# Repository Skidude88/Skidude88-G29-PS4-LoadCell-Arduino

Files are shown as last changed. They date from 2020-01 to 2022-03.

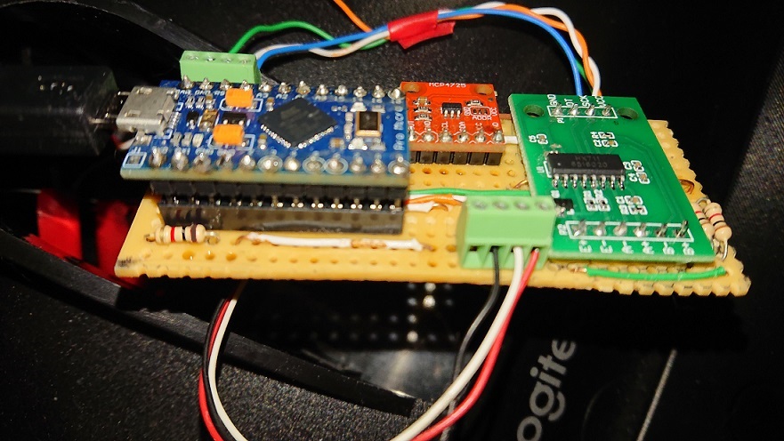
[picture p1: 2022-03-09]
img/Final Build - Clutch Resistor.jpg

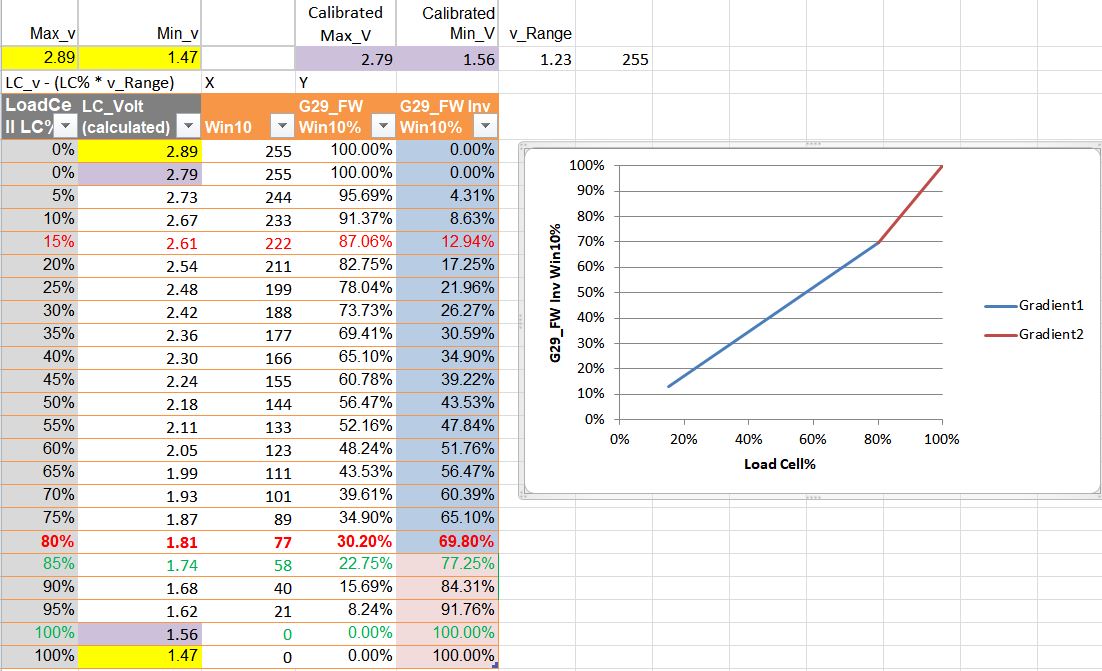
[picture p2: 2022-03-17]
img/New Testing.JPG

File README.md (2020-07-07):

# Skidude88-G29-PS4-LoadCell-Arduino
DIY load cell conversion for Logitech G29 on PS4 using Arduino Pro Micro. On Gran Tourismo Sport, where no manual in-game device calibration is availiable.

This Project was developed in conjunction with an analog DIY load cell version by GeekyDeaks

https://github.com/GeekyDeaks/g29-load-cell

# For full info on this project please refer to the project Wiki Pages

The final working project is with a single load cell and a MCP4725 - DAC

For the Pedal 3D print files - Please see the aforementioned GeekyDeaks project pages

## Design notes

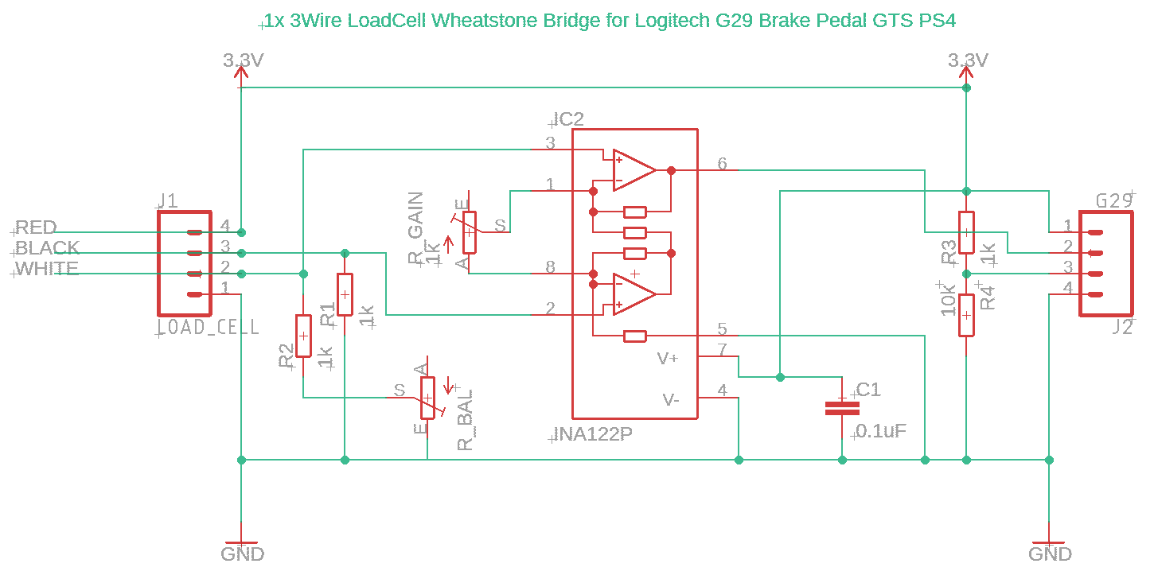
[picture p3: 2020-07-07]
img/Single 3WireLoadCellSchematic.PNG

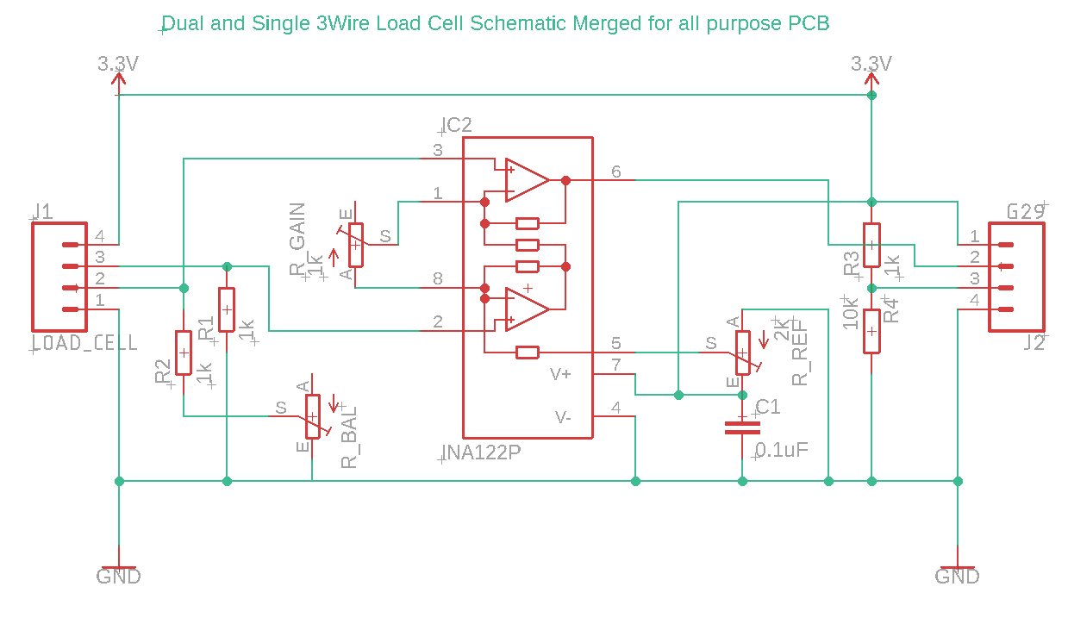
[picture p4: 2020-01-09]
img/Dual and Single LoadCell Schematic For MultiPurp PCB.PNG

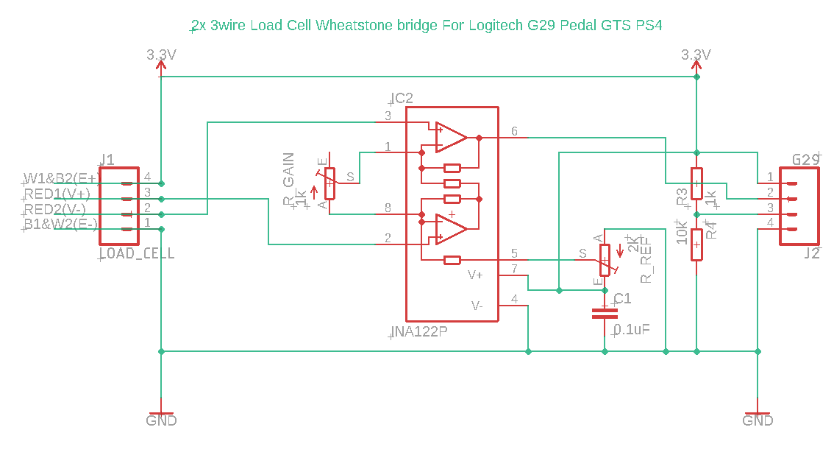
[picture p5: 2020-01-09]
img/2x3WireLoadCellSchematic.PNG

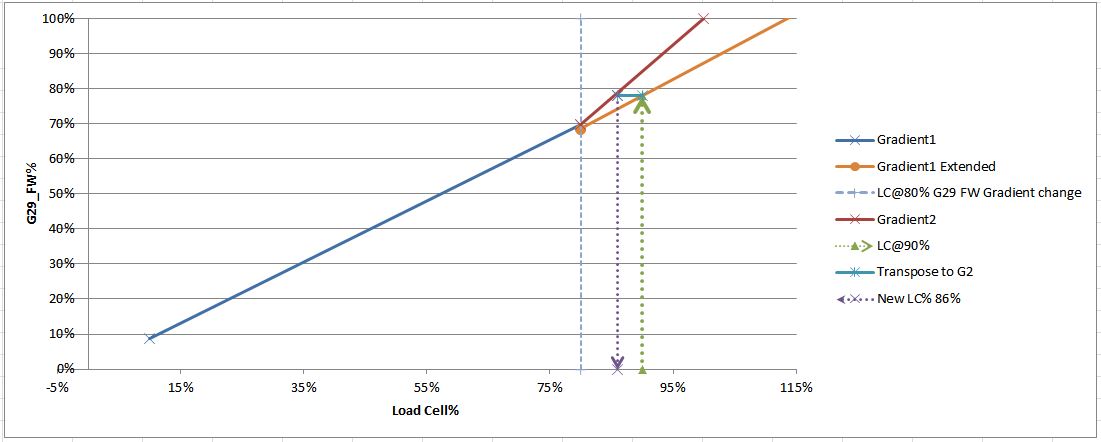
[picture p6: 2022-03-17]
img/New Table-Graph.JPG

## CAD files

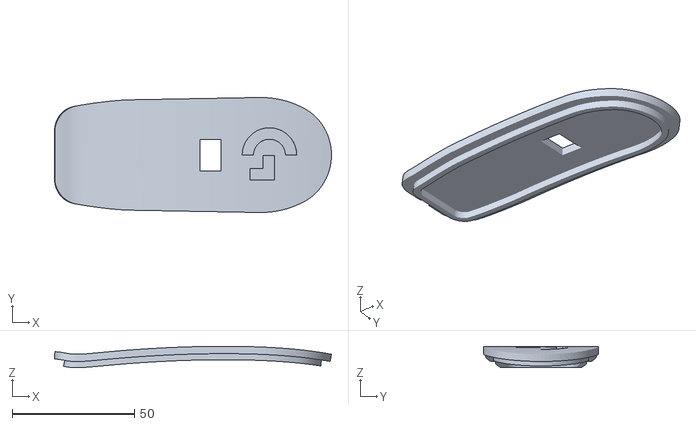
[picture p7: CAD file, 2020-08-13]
stl/G29 Brake Pedal Cover - USB.stl
113.1 x 47.0 x 8.76

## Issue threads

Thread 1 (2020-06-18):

PC/PS4 and G25/G27/G29 Compatibility.

isopix, 2020-06-18:
Hi,

I guess that yes, but wanted to make sure that's compatible with both PC and PS4 without any recalibration? Is it WIP, or is it solution that already progress.

I'm also wondering if it's needed only for G29 pedals because progressive brake curve(so called 'load cell emulation'), and without your board cell-modded G25/G27 pedals would work without any issues?

Overally your repo lacks clear documentation, or at least easy readme which would point to correct schematic/code/firmware blob. I saw different schematics, one with four chips/two arduinos(I don't understand what 'IPS' there means) and I don't know which should I use/ what should I buy.

Anyway thanks for your great work!

GeekyDeaks, 2020-06-18:
Hey @isopix - not sure if you found it, but @Skidude88 put most of his thoughts in the wiki rather than the README https://github.com/Skidude88/Skidude88-G29-PS4-LoadCell-Arduino/wiki

His design worked by emulating the voltage levels of the standard pot, so that the pedals could still be directly connected to the G29 wheel.  I believe you can tweak the constants for the max and min in the code e.g.

https://github.com/Skidude88/Skidude88-G29-PS4-LoadCell-Arduino/blob/5b6c035fbedb372972704d26ac1def72356d9f96/Code/SimPedal_ver3_dac.ino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

Please note that it's not actually trying to workaround the progressive brake curve of the G29, but it could in theory.  The circuit would still be required for a G25/G27 since the loadcell used is just a pair of resistors that change value by a very small amount when a load is applied, so you need something to measure the change and convert it to a voltage

I think when you mentioned IPS you may have been referring to the ISP code?  This is an auxillary arduino project that turns an arduino into an in-circuit programmer.  I this was required because the G29 actually supplies 3.3v to the pedals, and the arduino used needed some fuses set to work properly at 3.3v and they could not be set via the bootloader mechanism, so a spare arduino was configured as an ISP to program the target arduino, which is probably why you see two of them!

Skidude88, 2020-06-18:
Hi isopix,

Thanks for pointing out the IPS file name typo - should be "ISP" - In System Programmer - detailed in the 2nd Wiki: here:

[https://github.com/Skidude88/Skidude88-G29-PS4-LoadCell-Arduino/wiki/Arduino-Pro-Micro-with-a-Broken-USB-connector](url)

I only used two Arduino's after breaking the original.  The wiki on how to use a 2nd Arduino to Program another was included as an out of interest additional, sub project.

I can't see why it wouldn't work on a PC, the mod is only replacing the variable resistor pot , spring & flaky rubber block - converting the load cell output to voltage values required. The PC wouldn't know any different.

The project wasn't used\tested\tried on one. I only ran on a PS4 and Gran Turismo Sport.

I've made a few tweaks to the wiki , that may  (or may not) make things a little clearer!

Skidude88, 2020-06-18:
Re WIP

This was a finished project.

Though I am running @GeekyDeaks Analogue version of our project - only because we'd tinkered making home made PCBs .

And it's just a bit of a faff to keep connecting up the 2nd Arduino to program the  other and setting the 5v board to run a 3.3v (and the lower frequency) each time.

If I'd got a 3.3v board version I'd probably run with that as it just connect straight up to USB on PC

isopix, 2020-06-18:
Ok, thank you both for the reply. I didn't know about the Wiki there.

I found @GeekyDeaks your repo yesterday and that you are selling PCBs for it. Wanted to ask if you live within EU and what would be the price of PCB with shipping to Poland. I've later found TrueBrake and now not sure what to choose:

1) GeekyDeaks DIY LoadCell
+ real load cell (much more reliable than any pot-based solution?)
+ ?price (it's unknown ;-)
- not compact DIY hard to install
- 3D printed body(fragile?)
- not G29 firendly because progressive curve, but according to @GeekyDeaks it can be corrected in firmware

2) TrueBrake
+ easy to install
+ durable body
+ compact
- not really G29  friendly(because G29 pedals firmware[or maybe it's wheel firmware?) output got progressive curve, and it's dumb pot output)
- not real load cell
- pot based(and whe know that pot wears after time. Why not hall-effect rotary position sensor in place of pot?) Is it easy to buy off-the-shelf part?
- pricey (mine g29+shifter+stand in mint condition costed 120GBP, while TrueBrake costs 71GBP with VAT+shipping to Poland)

3) Ricmotech LC27 Load Cell Conversion Kit
+ real load cell
+ ricmotech quality
+ compact and easy to install
- not really G29  friendly(because G29 pedals firmware[or maybe it's wheel firmware?) output got progressive curve, and it's dumb pot output)
- $130 is nearly as much as  I've paid for G29+shifter+stand combo, so it's proabably designed

So as I understand no solution would be ideal with G29 progressive output curve in firmware, so maybe the best idea would be to exchange G29 pedals for G27 one, which got linear output curve, right? (Or maybe G27 pedals firmware could be dumped and programmed into G29? or maybe it's wheel firmware, not pedals firmware?)

I will post this questions in racedepartment too, wonder about AXC SIM's response.

GeekyDeaks, 2020-06-18:
Hi @isopix

I would not worry too much about the mapping of the G29 wheel on the brake voltage. output.  We plotted it out and it's not particularly aggressive and more a gentle curve.

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

If you plan to use it with a PC and you have a spare arduino, then you might want to consider something like this to bypass the wheel https://github.com/n-e-y-s/G27_Pedals_and_Shifter

TrueBrake is a fairly low-cost option, especially if you just want to improve the pedal and not take on a project to tinker with! :). It is still a pot, but it's not as exposed as those in the G29/G27 etc, so I would not expect it to suffer the same issues with dust.

If you want to go the DIY option and would like a PCB, PM me in racedepartment and I'll post one over foc.

Skidude88, 2020-06-19:
The 3D printed body is REALLY tough. A friend made it, so I can't give specifics on the type of plastic material used.

GeekyDeaks, 2020-06-19:
I'm surprised you did not elaborate on the reason why you know first hand that it's really tough 😄

Skidude88, 2020-06-19:
Ha!  I originally put I've a scar to prove it, but deleted the comment 😄

jhoman81, 2020-07-04:
I have a few questions about this setup. First, should this work without any modifications with the G27? I don't know enough about electronics to even know where to start looking for the answer to that question so hopefully you have some insight. Also, is the hx711 library you're using the one referenced in the file (https://github.com/aguegu/ardulibs/tree/master/hx711) or the one from https://github.com/bogde/HX711, because I can only get it to verify/upload with the latter. Finally, does it have to be connected to the G27/G29 do get values through the serial port? I think I have mine wired up correctly but I have getting 0 information back from the serial monitor. Any help is greatly appreciated! Thanks!

Skidude88, 2020-07-05:
Hi Joshua,

I can't find your message on github, despite selecting the "view it on Github" on the email (I'm new to Github! )

I couldn't recall where the libraries are - so I've just quickly loaded up and complied with the debugger on...

I believe you're correct - I have incorrectly listed the library!

The compiler references : HX711-0.7.3@0.7.2 - Which a quick google seems to be the bogde you've mentioned.

I'll get the wiki and code updated asap!

With regards to your other questions :

I only have a G29, so can't confirm that the voltages the G27 pedal outputs are the same as the G29.

From memory the G29 off is 3.1v and 100% brake on was around 2v

Someone might have posted on the web the values for the G27 - so a bit of googling might be required.

Or with a multi-meter you could check your pedal's pot voltage output.

If the voltages are different then it would just be a case of changing the BrakeFull_v and BrakeOff_v variable values in the code to suit.

The project doesn't need to be connected up to the wheel to see the calculated values on the serial monitor\plotter, just enable the relevant serial.println line in the code  (depending on what value you want to monitor : BrakeValue or Percent)

Kind Regards,

James

________________________________
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

jhoman81, 2020-07-07:
Hola James,

Sorry! It was late and I wanted to make sure I had done everything correctly so I deleted the old post. What you posted, however, is extremely helpful! Thanks! I should have some free time to try this out tomorrow with the G27 pedals and will let you know what I figure out. I've gone ahead and forked your repository to begin shifting it to the G27. Thanks again!

Saludos,
Josh

GeekyDeaks, 2020-07-08:
Hi Josh,

I'm assuming you are using this on a PC?  If so, I also have another suggestion, but feel free to ignore it :)

A lot of the hard work James did was in getting a correct and stable voltage out of the Arduino for the ADC in the wheel to read so it could still be used on a PS4.  If you are on PC, then you have the option to connect the pedals directly to the PC using the Arduino to emulate a game controller (e.g. https://github.com/functionreturnfunction/G27_Pedals_and_Shifter) adding the code James created to read the HX711 as one of the axis.

This makes the entire solution digital, removing the need for the DAC or the low pass filter with PWM.  This will simplify the circuit and give you a little more flexibility with the pedal ranges, but it also means you have more work to do in the software instead

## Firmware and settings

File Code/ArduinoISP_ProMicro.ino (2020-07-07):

// ArduinoISP
// Copyright (c) 2008-2011 Randall Bohn
// If you require a license, see
// http://www.opensource.org/licenses/bsd-license.php
//
// This sketch turns the Arduino into a AVRISP using the following Arduino pins:
//
// Pin 10 is used to reset the target microcontroller.
//
// By default, the hardware SPI pins MISO, MOSI and SCK are used to communicate
// with the target. On all Arduinos, these pins can be found
// on the ICSP/SPI header:
//
//               MISO °. . 5V (!) Avoid this pin on Due, Zero...
//               SCK   . . MOSI
//                     . . GND
//
// On some Arduinos (Uno,...), pins MOSI, MISO and SCK are the same pins as
// digital pin 11, 12 and 13, respectively. That is why many tutorials instruct
// you to hook up the target to these pins. If you find this wiring more
// practical, have a define USE_OLD_STYLE_WIRING. This will work even when not
// using an Uno. (On an Uno this is not needed).
//
// Alternatively you can use any other digital pin by configuring
// software ('BitBanged') SPI and having appropriate defines for PIN_MOSI,
// PIN_MISO and PIN_SCK.
//
// IMPORTANT: When using an Arduino that is not 5V tolerant (Due, Zero, ...) as
// the programmer, make sure to not expose any of the programmer's pins to 5V.
// A simple way to accomplish this is to power the complete system (programmer
// and target) at 3V3.
//
// Put an LED (with resistor) on the following pins:
// 9: Heartbeat   - shows the programmer is running
// 8: Error       - Lights up if something goes wrong (use red if that makes sense)
// 7: Programming - In communication with the slave
//

#include "Arduino.h"
#undef SERIAL


#define PROG_FLICKER true

// Configure SPI clock (in Hz).
// E.g. for an ATtiny @ 128 kHz: the datasheet states that both the high and low
// SPI clock pulse must be > 2 CPU cycles, so take 3 cycles i.e. divide target
// f_cpu by 6:
//     #define SPI_CLOCK            (128000/6)
//
// A clock slow enough for an ATtiny85 @ 1 MHz, is a reasonable default:

#define SPI_CLOCK 		(1000000/6)


// Select hardware or software SPI, depending on SPI clock.
// Currently only for AVR, for other architectures (Due, Zero,...), hardware SPI
// is probably too fast anyway.

#if defined(ARDUINO_ARCH_AVR)

#if SPI_CLOCK > (F_CPU / 128)
#define USE_HARDWARE_SPI
#endif

#endif

// Configure which pins to use:

// The standard pin configuration.
#ifndef ARDUINO_HOODLOADER2

#define RESET     10 // Use pin 10 to reset the target rather than SS
#define LED_HB    9
#define LED_ERR   8
#define LED_PMODE 7

// Uncomment following line to use the old Uno style wiring
// (using pin 11, 12 and 13 instead of the SPI header) on Leonardo, Due...

#define USE_OLD_STYLE_WIRING

#ifdef USE_OLD_STYLE_WIRING

//#define PIN_MOSI	11
//#define PIN_MISO	12
//#define PIN_SCK		13

#define PIN_MOSI  16
#define PIN_MISO  14
#define PIN_SCK   15


#endif

// HOODLOADER2 means running sketches on the ATmega16U2 serial converter chips
// on Uno or Mega boards. We must use pins that are broken out:
#else

#define RESET     	4
#define LED_HB    	7
#define LED_ERR   	6
#define LED_PMODE 	5

#endif

// By default, use hardware SPI pins:
#ifndef PIN_MOSI
#define PIN_MOSI 	MOSI
#endif

#ifndef PIN_MISO
#define PIN_MISO 	MISO
#endif

#ifndef PIN_SCK
#define PIN_SCK 	SCK
#endif

// Force bitbanged SPI if not using the hardware SPI pins:
#if (PIN_MISO != MISO) ||  (PIN_MOSI != MOSI) || (PIN_SCK != SCK)
#undef USE_HARDWARE_SPI
#endif


// Configure the serial port to use.
//
// Prefer the USB virtual serial port (aka. native USB port), if the Arduino has one:
//   - it does not autoreset (except for the magic baud rate of 1200).
//   - it is more reliable because of USB handshaking.
//
// Leonardo and similar have an USB virtual serial port: 'Serial'.
// Due and Zero have an USB virtual serial port: 'SerialUSB'.
//
// On the Due and Zero, 'Serial' can be used too, provided you disable autoreset.
// To use 'Serial': #define SERIAL Serial

#ifdef SERIAL_PORT_USBVIRTUAL
#define SERIAL SERIAL_PORT_USBVIRTUAL
#else
#define SERIAL Serial
#endif


// Configure the baud rate:

#define BAUDRATE	19200
// #define BAUDRATE	115200
// #define BAUDRATE	1000000


#define HWVER 2
#define SWMAJ 1
#define SWMIN 18

// STK Definitions
#define STK_OK      0x10
#define STK_FAILED  0x11
#define STK_UNKNOWN 0x12
#define STK_INSYNC  0x14
#define STK_NOSYNC  0x15
#define CRC_EOP     0x20 //ok it is a space...

void pulse(int pin, int times);

#ifdef USE_HARDWARE_SPI
#include "SPI.h"
#else

#define SPI_MODE0 0x00

class SPISettings {
  public:
    // clock is in Hz
    SPISettings(uint32_t clock, uint8_t bitOrder, uint8_t dataMode) : clock(clock) {
      (void) bitOrder;
      (void) dataMode;
    };

  private:
    uint32_t clock;

    friend class BitBangedSPI;
};

class BitBangedSPI {
  public:
    void begin() {
      digitalWrite(PIN_SCK, LOW);
      digitalWrite(PIN_MOSI, LOW);
      pinMode(PIN_SCK, OUTPUT);
      pinMode(PIN_MOSI, OUTPUT);
      pinMode(PIN_MISO, INPUT);
    }

    void beginTransaction(SPISettings settings) {
      pulseWidth = (500000 + settings.clock - 1) / settings.clock;
      if (pulseWidth == 0)
        pulseWidth = 1;
    }

    void end() {}

    uint8_t transfer (uint8_t b) {
      for (unsigned int i = 0; i < 8; ++i) {
        digitalWrite(PIN_MOSI, (b & 0x80) ? HIGH : LOW);
        digitalWrite(PIN_SCK, HIGH);
        delayMicroseconds(pulseWidth);
        b = (b << 1) | digitalRead(PIN_MISO);
        digitalWrite(PIN_SCK, LOW); // slow pulse
        delayMicroseconds(pulseWidth);
      }
      return b;
    }

  private:
    unsigned long pulseWidth; // in microseconds
};

static BitBangedSPI SPI;

#endif

void setup() {
  SERIAL.begin(BAUDRATE);

  pinMode(LED_PMODE, OUTPUT);
  pulse(LED_PMODE, 2);
  pinMode(LED_ERR, OUTPUT);
  pulse(LED_ERR, 2);
  pinMode(LED_HB, OUTPUT);
  pulse(LED_HB, 2);

}

int error = 0;
int pmode = 0;
// address for reading and writing, set by 'U' command
unsigned int here;
uint8_t buff[256]; // global block storage

#define beget16(addr) (*addr * 256 + *(addr+1) )
typedef struct param {
  uint8_t devicecode;
  uint8_t revision;
  uint8_t progtype;
  uint8_t parmode;
  uint8_t polling;
  uint8_t selftimed;
  uint8_t lockbytes;
  uint8_t fusebytes;
  uint8_t flashpoll;
  uint16_t eeprompoll;
  uint16_t pagesize;
  uint16_t eepromsize;
  uint32_t flashsize;
}
parameter;

parameter param;

// this provides a heartbeat on pin 9, so you can tell the software is running.
uint8_t hbval = 128;
int8_t hbdelta = 8;
void heartbeat() {
  static unsigned long last_time = 0;
  unsigned long now = millis();
  if ((now - last_time) < 40)
    return;
  last_time = now;
  if (hbval > 192) hbdelta = -hbdelta;
  if (hbval < 32) hbdelta = -hbdelta;
  hbval += hbdelta;
  analogWrite(LED_HB, hbval);
}

static bool rst_active_high;

void reset_target(bool reset) {
  digitalWrite(RESET, ((reset && rst_active_high) || (!reset && !rst_active_high)) ? HIGH : LOW);
}

void loop(void) {
  // is pmode active?
  if (pmode) {
    digitalWrite(LED_PMODE, HIGH);
  } else {
    digitalWrite(LED_PMODE, LOW);
  }
  // is there an error?
  if (error) {
    digitalWrite(LED_ERR, HIGH);
  } else {
    digitalWrite(LED_ERR, LOW);
  }

  // light the heartbeat LED
  heartbeat();
  if (SERIAL.available()) {
    avrisp();
  }
}

uint8_t getch() {
  while (!SERIAL.available());
  return SERIAL.read();
}
void fill(int n) {
  for (int x = 0; x < n; x++) {
    buff[x] = getch();
  }
}

#define PTIME 30
void pulse(int pin, int times) {
  do {
    digitalWrite(pin, HIGH);
    delay(PTIME);
    digitalWrite(pin, LOW);
    delay(PTIME);
  } while (times--);
}

void prog_lamp(int state) {
  if (PROG_FLICKER) {
    digitalWrite(LED_PMODE, state);
  }
}

uint8_t spi_transaction(uint8_t a, uint8_t b, uint8_t c, uint8_t d) {
  SPI.transfer(a);
  SPI.transfer(b);
  SPI.transfer(c);
  return SPI.transfer(d);
}

void empty_reply() {
  if (CRC_EOP == getch()) {
    SERIAL.print((char)STK_INSYNC);
    SERIAL.print((char)STK_OK);
  } else {
    error++;
    SERIAL.print((char)STK_NOSYNC);
  }
}

void breply(uint8_t b) {
  if (CRC_EOP == getch()) {
    SERIAL.print((char)STK_INSYNC);
    SERIAL.print((char)b);
    SERIAL.print((char)STK_OK);
  } else {
    error++;
    SERIAL.print((char)STK_NOSYNC);
  }
}

void get_version(uint8_t c) {
  switch (c) {
    case 0x80:
      breply(HWVER);
      break;
    case 0x81:
      breply(SWMAJ);
      break;
    case 0x82:
      breply(SWMIN);
      break;
    case 0x93:
      breply('S'); // serial programmer
      break;
    default:
      breply(0);
  }
}

void set_parameters() {
  // call this after reading parameter packet into buff[]
  param.devicecode = buff[0];
  param.revision   = buff[1];
  param.progtype   = buff[2];
  param.parmode    = buff[3];
  param.polling    = buff[4];
  param.selftimed  = buff[5];
  param.lockbytes  = buff[6];
  param.fusebytes  = buff[7];
  param.flashpoll  = buff[8];
  // ignore buff[9] (= buff[8])
  // following are 16 bits (big endian)
  param.eeprompoll = beget16(&buff[10]);
  param.pagesize   = beget16(&buff[12]);
  param.eepromsize = beget16(&buff[14]);

  // 32 bits flashsize (big endian)
  param.flashsize = buff[16] * 0x01000000
                    + buff[17] * 0x00010000
                    + buff[18] * 0x00000100
                    + buff[19];

  // AVR devices have active low reset, AT89Sx are active high
  rst_active_high = (param.devicecode >= 0xe0);
}

void start_pmode() {

  // Reset target before driving PIN_SCK or PIN_MOSI

  // SPI.begin() will configure SS as output, so SPI master mode is selected.
  // We have defined RESET as pin 10, which for many Arduinos is not the SS pin.
  // So we have to configure RESET as output here,
  // (reset_target() first sets the correct level)
  reset_target(true);
  pinMode(RESET, OUTPUT);
  SPI.begin();
  SPI.beginTransaction(SPISettings(SPI_CLOCK, MSBFIRST, SPI_MODE0));

  // See AVR datasheets, chapter "SERIAL_PRG Programming Algorithm":

  // Pulse RESET after PIN_SCK is low:
  digitalWrite(PIN_SCK, LOW);
  delay(20); // discharge PIN_SCK, value arbitrarily chosen
  reset_target(false);
  // Pulse must be minimum 2 target CPU clock cycles so 100 usec is ok for CPU
  // speeds above 20 KHz
  delayMicroseconds(100);
  reset_target(true);

  // Send the enable programming command:
  delay(50); // datasheet: must be > 20 msec
  spi_transaction(0xAC, 0x53, 0x00, 0x00);
  pmode = 1;
}

void end_pmode() {
  SPI.end();
  // We're about to take the target out of reset so configure SPI pins as input
  pinMode(PIN_MOSI, INPUT);
  pinMode(PIN_SCK, INPUT);
  reset_target(false);
  pinMode(RESET, INPUT);
  pmode = 0;
}

void universal() {
  uint8_t ch;

  fill(4);
  ch = spi_transaction(buff[0], buff[1], buff[2], buff[3]);
  breply(ch);
}

void flash(uint8_t hilo, unsigned int addr, uint8_t data) {
  spi_transaction(0x40 + 8 * hilo,
                  addr >> 8 & 0xFF,
                  addr & 0xFF,
                  data);
}
void commit(unsigned int addr) {
  if (PROG_FLICKER) {
    prog_lamp(LOW);
  }
  spi_transaction(0x4C, (addr >> 8) & 0xFF, addr & 0xFF, 0);
  if (PROG_FLICKER) {
    delay(PTIME);
    prog_lamp(HIGH);
  }
}

unsigned int current_page() {
  if (param.pagesize == 32) {
    return here & 0xFFFFFFF0;
  }
  if (param.pagesize == 64) {
    return here & 0xFFFFFFE0;
  }
  if (param.pagesize == 128) {
    return here & 0xFFFFFFC0;
  }
  if (param.pagesize == 256) {
    return here & 0xFFFFFF80;
  }
  return here;
}


void write_flash(int length) {
  fill(length);
  if (CRC_EOP == getch()) {
    SERIAL.print((char) STK_INSYNC);
    SERIAL.print((char) write_flash_pages(length));
  } else {
    error++;
    SERIAL.print((char) STK_NOSYNC);
  }
}

uint8_t write_flash_pages(int length) {
  int x = 0;
  unsigned int page = current_page();
  while (x < length) {
    if (page != current_page()) {
      commit(page);
      page = current_page();
    }
    flash(LOW, here, buff[x++]);
    flash(HIGH, here, buff[x++]);
    here++;
  }

  commit(page);

  return STK_OK;
}

#define EECHUNK (32)
uint8_t write_eeprom(unsigned int length) {
  // here is a word address, get the byte address
  unsigned int start = here * 2;
  unsigned int remaining = length;
  if (length > param.eepromsize) {
    error++;
    return STK_FAILED;
  }
  while (remaining > EECHUNK) {
    write_eeprom_chunk(start, EECHUNK);
    start += EECHUNK;
    remaining -= EECHUNK;
  }
  write_eeprom_chunk(start, remaining);
  return STK_OK;
}
// write (length) bytes, (start) is a byte address
uint8_t write_eeprom_chunk(unsigned int start, unsigned int length) {
  // this writes byte-by-byte, page writing may be faster (4 bytes at a time)
  fill(length);
  prog_lamp(LOW);
  for (unsigned int x = 0; x < length; x++) {
    unsigned int addr = start + x;
    spi_transaction(0xC0, (addr >> 8) & 0xFF, addr & 0xFF, buff[x]);
    delay(45);
  }
  prog_lamp(HIGH);
  return STK_OK;
}

void program_page() {
  char result = (char) STK_FAILED;
  unsigned int length = 256 * getch();
  length += getch();
  char memtype = getch();
  // flash memory @here, (length) bytes
  if (memtype == 'F') {
    write_flash(length);
    return;
  }
  if (memtype == 'E') {
    result = (char)write_eeprom(length);
    if (CRC_EOP == getch()) {
      SERIAL.print((char) STK_INSYNC);
      SERIAL.print(result);
    } else {
      error++;
      SERIAL.print((char) STK_NOSYNC);
    }
    return;
  }
  SERIAL.print((char)STK_FAILED);
  return;
}

uint8_t flash_read(uint8_t hilo, unsigned int addr) {
  return spi_transaction(0x20 + hilo * 8,
                         (addr >> 8) & 0xFF,
                         addr & 0xFF,
                         0);
}

char flash_read_page(int length) {
  for (int x = 0; x < length; x += 2) {
    uint8_t low = flash_read(LOW, here);
    SERIAL.print((char) low);
    uint8_t high = flash_read(HIGH, here);
    SERIAL.print((char) high);
    here++;
  }
  return STK_OK;
}

char eeprom_read_page(int length) {
  // here again we have a word address
  int start = here * 2;
  for (int x = 0; x < length; x++) {
    int addr = start + x;
    uint8_t ee = spi_transaction(0xA0, (addr >> 8) & 0xFF, addr & 0xFF, 0xFF);
    SERIAL.print((char) ee);
  }
  return STK_OK;
}

void read_page() {
  char result = (char)STK_FAILED;
  int length = 256 * getch();
  length += getch();
  char memtype = getch();
  if (CRC_EOP != getch()) {
    error++;
    SERIAL.print((char) STK_NOSYNC);
    return;
  }
  SERIAL.print((char) STK_INSYNC);
  if (memtype == 'F') result = flash_read_page(length);
  if (memtype == 'E') result = eeprom_read_page(length);
  SERIAL.print(result);
}

void read_signature() {
  if (CRC_EOP != getch()) {
    error++;
    SERIAL.print((char) STK_NOSYNC);
    return;
  }
  SERIAL.print((char) STK_INSYNC);
  uint8_t high = spi_transaction(0x30, 0x00, 0x00, 0x00);
  SERIAL.print((char) high);
  uint8_t middle = spi_transaction(0x30, 0x00, 0x01, 0x00);
  SERIAL.print((char) middle);
  uint8_t low = spi_transaction(0x30, 0x00, 0x02, 0x00);
  SERIAL.print((char) low);
  SERIAL.print((char) STK_OK);
}
//////////////////////////////////////////
//////////////////////////////////////////


////////////////////////////////////
////////////////////////////////////
void avrisp() {
  uint8_t ch = getch();
  switch (ch) {
    case '0': // signon
      error = 0;
      empty_reply();
      break;
    case '1':
      if (getch() == CRC_EOP) {
        SERIAL.print((char) STK_INSYNC);
        SERIAL.print("AVR ISP");
        SERIAL.print((char) STK_OK);
      }
      else {
        error++;
        SERIAL.print((char) STK_NOSYNC);
      }
      break;
    case 'A':
      get_version(getch());
      break;
    case 'B':
      fill(20);
      set_parameters();
      empty_reply();
      break;
    case 'E': // extended parameters - ignore for now
      fill(5);
      empty_reply();
      break;
    case 'P':
      if (!pmode)
        start_pmode();
      empty_reply();
      break;
    case 'U': // set address (word)
      here = getch();
      here += 256 * getch();
      empty_reply();
      break;

    case 0x60: //STK_PROG_FLASH
      getch(); // low addr
      getch(); // high addr
      empty_reply();
      break;
    case 0x61: //STK_PROG_DATA
      getch(); // data
      empty_reply();
      break;

    case 0x64: //STK_PROG_PAGE
      program_page();
      break;

    case 0x74: //STK_READ_PAGE 't'
      read_page();
      break;

    case 'V': //0x56
      universal();
      break;
    case 'Q': //0x51
      error = 0;
      end_pmode();
      empty_reply();
      break;

    case 0x75: //STK_READ_SIGN 'u'
      read_signature();
      break;

    // expecting a command, not CRC_EOP
    // this is how we can get back in sync
    case CRC_EOP:
      error++;
      SERIAL.print((char) STK_NOSYNC);
      break;

    // anything else we will return STK_UNKNOWN
    default:
      error++;
      if (CRC_EOP == getch())
        SERIAL.print((char)STK_UNKNOWN);
      else
        SERIAL.print((char)STK_NOSYNC);
  }
}

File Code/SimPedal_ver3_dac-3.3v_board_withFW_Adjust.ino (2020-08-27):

// Pedal Gradient Maths
// Back to school....
// Using DiView 2 linear gradients were determine as being used. Gradient2 being the informous brake grab\rubber bung fudge
// Sample data :
// Gradient1 (noted from 0% - around 70%) 
// x1 (G29% output) = 0.0706, y1 (LC %) =  0.15
// x2 = 0.6843, y2 = 0.8
// x2-x1 = 0.6137, y2-y1 = 0.65
// gradient1 (m1) = 0.65/0.6137 = 1.0591
// y_intersect (b1) = y1-(m1*x1)
// b1 = 0.0752
//
// Gradient2 (noted from around 70% - 100% brake) 
// x1 (G29% output) = 0.7235, y1 (LC %) = 0.825
// x2 = 1, y2 = 1
// x2-x1 = 0.2765, y2-y1 = .175
// gradient1 (m2) = 0.175/0.2765 = 0.6329
// y_intersect (b2) = y1-(m1*x1)
// b2 = 0.3671
//
// Gradient1 & Gradient2 intersect - using y = mx+b
// y = (1.0591 * x) + 0.0752
// and
// y = (0.6329 * x) + 0.3671
// (1.0591 * x) + 0.0752 = (0.6329 * x) + 0.3671
// (1.0591 * x) - (0.6329 * x) = 0.3671 - 0.0752
// (1.0591 * x) - (0.6329 * x) = 0.2919
//  0.4261 * x  = 0.2919
// Intersect x = 0.6848 (68.48%)
// y = (mx)+b  - using either gradient
// LC%_y = (m1  * .6848) +b1
// LC%_y = (1.0591 * 0.6848) + 0.0752 = 0.8004 (80%)

// Code for 3.3v Micro Pro Board with 1x load cell, 1x HX711 module and 1x MCP4725 DAC

#include <HX711.h>    // HX711-0.7.3.zip
#include <Wire.h>     //Include the Wire library to talk I2C
//#include <avr/power.h> // Was needed for the 5v board and div2, now using 3.3v board

//This is the I2C Address of the MCP4725, by default (A0 pulled to GND).
//Please note that this breakout is for the MCP4725A0. 
#define MCP4725_ADDR 0x60   
//For devices with A0 pulled HIGH, use 0x61
// MCP4725 is 12bit inout and output at default 100Kbps (also available 400Kbps mode)

// How many samples to take at initialization of the library to zero
// out the offset of the load cell.
const int BRAKE_PEDAL_LOAD_CELL_TARE_REPS =  10;

// Arbitary scaling 1100. Single Load Cell.
// Testing with set at 1100, pressing hard -  max brake_value is a value around 400 to 800 
const int BRAKE_PEDAL_LOAD_CELL_SCALING =  1100;

// LOCAL VARIABLES

// HX711 circuit wiring
const int LOADCELL_DOUT_PIN = 1;
const int LOADCELL_SCK_PIN = 0;

const float brakemax = -600; //comfortably pressing hard on load cell, with single cell, inverted is -400. To Stiffen brake go down to -800
const float arduino_vcc = 3.3; //G29 3.3v
const float G29BrakeFull_v = 1.48;
// GTS SPORT 2.86v to 1.93v
// ACC 2.88v to 1.49v - 18.08.2020 2.76v
// ACC 21.08.2020 2.89v off was too sensative, resting foot on pedal registered as brake slightly on. 
const float G29BrakeOff_v = 2.93;
const float dac_BrakeFullPerc = G29BrakeFull_v / arduino_vcc;
const float dac_BrakeOffPerc = G29BrakeOff_v / arduino_vcc;

const float dac_step = arduino_vcc / 4096;

const int dac_BrakeFull = G29BrakeFull_v / dac_step;  // Lower Voltage
const int dac_BrakeOff = G29BrakeOff_v / dac_step;    // Higher voltage
const int dac_Range = dac_BrakeOff - dac_BrakeFull;

// linear equation y = mx+b
const float base_gradient_m1 = 1.0591;
const float base_intersect_b1 = 0.0752;

const float adj_gradient_m2 = 0.6329;
const float adj_intersect_b2 = 0.3671;

HX711 brake_pedal;

unsigned int dacValue; 
byte buffer[3];  

void setup()

{
  // Div 2 was needed for 5v board , now using 3.3v board
  //Div_2 - 16MHz /2 = 8Mhz
  //clock_prescale_set(clock_div_2);
  
  // Zero the pedal offset. This is is to compensate for the own weight
  // of the pedal. It is important not to apply any force to the pedal
  // While this is happening
  brake_pedal.begin(LOADCELL_DOUT_PIN, LOADCELL_SCK_PIN);
  brake_pedal.tare(BRAKE_PEDAL_LOAD_CELL_TARE_REPS);
  
  Wire.begin();                       // Begins the I2C communication
  //TWBR = 12;                        // Seems OK at 100kbps, otherwise MCP4725 can run at 400KHz using TWBR=12
} 

void loop()

{
  int32_t brake_value;
  float LC_brakePercOn;
  float brakePercOn;
  float G29fw_Perc;

  buffer[0] = 0b01000000;            //Sets the buffer0 with control byte (010-Sets in Write mode)

  // Turn off Tx & RX LEDS
  TXLED0;
  RXLED0;
  
  brake_value = brake_pedal.get_value(1);
  
  brake_value /= BRAKE_PEDAL_LOAD_CELL_SCALING;
  brake_value *= -1; // invert so off pedal is a higher value (0) than full pedal 

  //brake_value = -300;
  
  if(brake_value > 0){
    brake_value = 0;
  }

  //Serial.println (brake_value);
  
  LC_brakePercOn = brake_value/brakemax; // determine applied brake pedal percentage(base gradient1)
  
  if (LC_brakePercOn > .8){
    // from 80% Calculate the G29fw_% using gradient1 and recalculate LC% using gradient2
    // x = (y-b)/m with gradient1
    G29fw_Perc = (LC_brakePercOn - base_intersect_b1) / base_gradient_m1;
    // y = (mx)+b with gradient2
    LC_brakePercOn = (adj_gradient_m2 * G29fw_Perc )+ adj_intersect_b2 ; 
  }
  //Serial.println(LC_brakePercOn);

  //LC_brakePercOn = .5;
  
  dacValue = dac_BrakeOff - (dac_Range *  LC_brakePercOn);

//diVIew
  //  dacValue = 3661;
  
  //  dacValue = 3339;
  //  dacValue = 3091;
  //  dacValue = 2842;
  //  dacValue = 2594;
   
  //  dacValue = 2346;
  //  dacValue = 2098;
  //  dacValue = 1974;
  //  dacValue = 1849;
  //  dacValue = 1837;

 //dacValue = 1837; // 1.48v

//ACC
  //dacValue = 3426; //2.76v
  //dacValue = 1849; //1.49v

  //  dacValue = 3415; // flicker red
  //  dacValue = 3636; 
  //  dacValue = 3388;
  //  dacValue = 3140;
  //  dacValue = 2892;
  //  dacValue = 2643;
  //  dacValue = 2395;
  //  dacValue = 2147;
  //  dacValue = 1850;
  //  dacValue = 1849;

// GTS
  //  dacValue = 3550; // Not On 
  //  dacValue = 3537; //ABS LED FLicker
  //  dacValue = 3636; 
  //  dacValue = 3388;
  //  dacValue = 3140;
  //  dacValue = 2892;
  //  dacValue = 2643;
  //  dacValue = 2395;
  //  dacValue = 2147;
  //  dacValue = 2395;
  //  dacValue = 1837;

  // Check not supplying over voltage
  if (dacValue * dac_step > G29BrakeOff_v) {
    dacValue = G29BrakeOff_v;
  }

  buffer[1] = dacValue >> 4;              //Puts the most significant bit values
  buffer[2] = dacValue << 4;              //Puts the Least significant bit values

  Wire.beginTransmission(MCP4725_ADDR);
  Wire.write(buffer[0]);            //Sends the control byte to I2C 
  Wire.write(buffer[1]);            //Sends the MSB to I2C 
  Wire.write(buffer[2]);            //Sends the LSB to I2C  
  Wire.endTransmission();

//  Serial.println(dacValue);
  
} 

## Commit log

2020-07-07 Create G29 Brake Pedal Cover - Notch-small v1.stl
    [G29 Brake Pedal Cover - Notch-small v1.stl]
2020-07-24 Create Proto Board.jpg
2020-07-24 Create Proto Board Underside (Flipped).jpg
2020-08-07 Testing Hooked up
    Board powered by USB,
    Clutch not connected yet as I've ran out of resistors
2020-08-07 Tidy up code
    Code was a bit vaugue and wrong!
    [IC2-Scanner.ino, SimPedal_ver3_dac-3.3v_board.ino, SimPedal_ver3_dac-5v_board.ino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]
2020-08-10 Pedal Voltage Data Charts
2020-08-13 Pedal Cover Printed
2020-08-13 USB hole removed from Cover
    [G29 Brake Pedal Cover - Notch-small v1.stl, G29 Brake Pedal Cover - USB.stl]
2020-08-18 Create Final Build - Clutch Resistor.jpg
2020-08-18 Update Final Build - Clutch Resistor.jpg
2022-03-09 Clutch resistor values added and corrected
2022-03-18 Update Calibration summary.JPG
